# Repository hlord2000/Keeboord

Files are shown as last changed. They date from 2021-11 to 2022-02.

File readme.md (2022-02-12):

# Keeboord
## Created for the [Mechanical Keyboard Club at Georgia Tech](https://www.instagram.com/gt.keyboards)
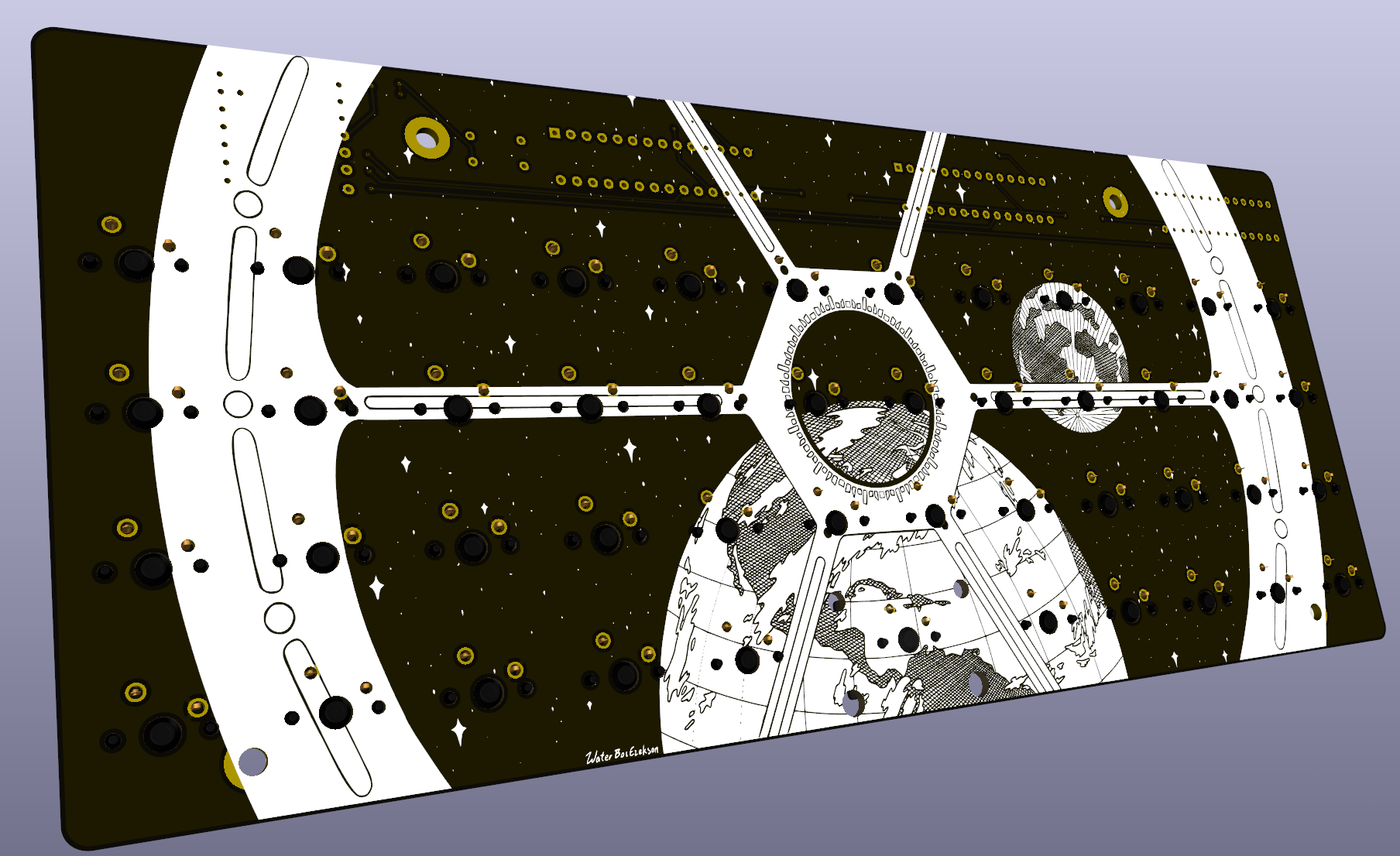
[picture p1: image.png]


This is a mechanical keyboard for Cherry switches.  It utilizes no diodes, instead registering button presses by using I2C I/O expanders.

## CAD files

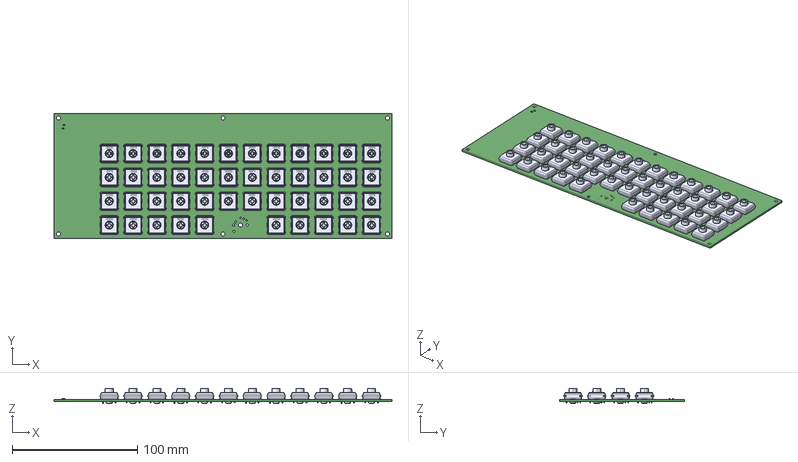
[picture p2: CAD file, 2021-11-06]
Hardware/keyboard.step
270.0 x 100.0 x 11.9 mm
AB2_SO28_W x 4

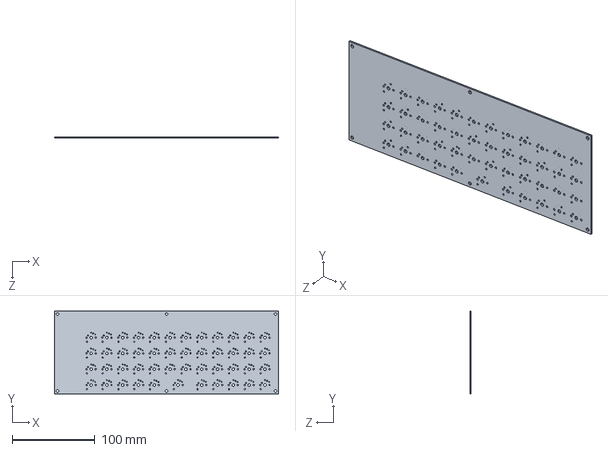
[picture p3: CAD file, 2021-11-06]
Case/COMPOUND_2.STEP
270.0 x 100.0 x 1.60 mm

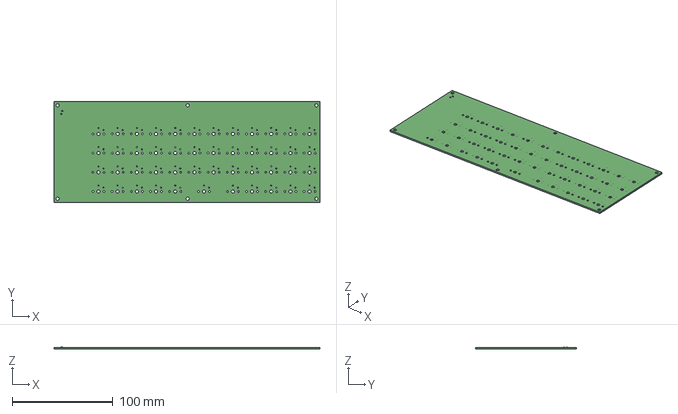
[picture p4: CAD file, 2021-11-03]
Case/keyboard.step
264.0 x 100.0 x 2.10 mm

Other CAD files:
Case/R_0603_1608Metric.SLDASM
Case/Kailh_PG1353.SLDASM
Case/SOLID.SLDPRT
Case/COMPOUND.SLDPRT
Case/COMPOUND_2.SLDPRT
Case/keyboard.SLDASM

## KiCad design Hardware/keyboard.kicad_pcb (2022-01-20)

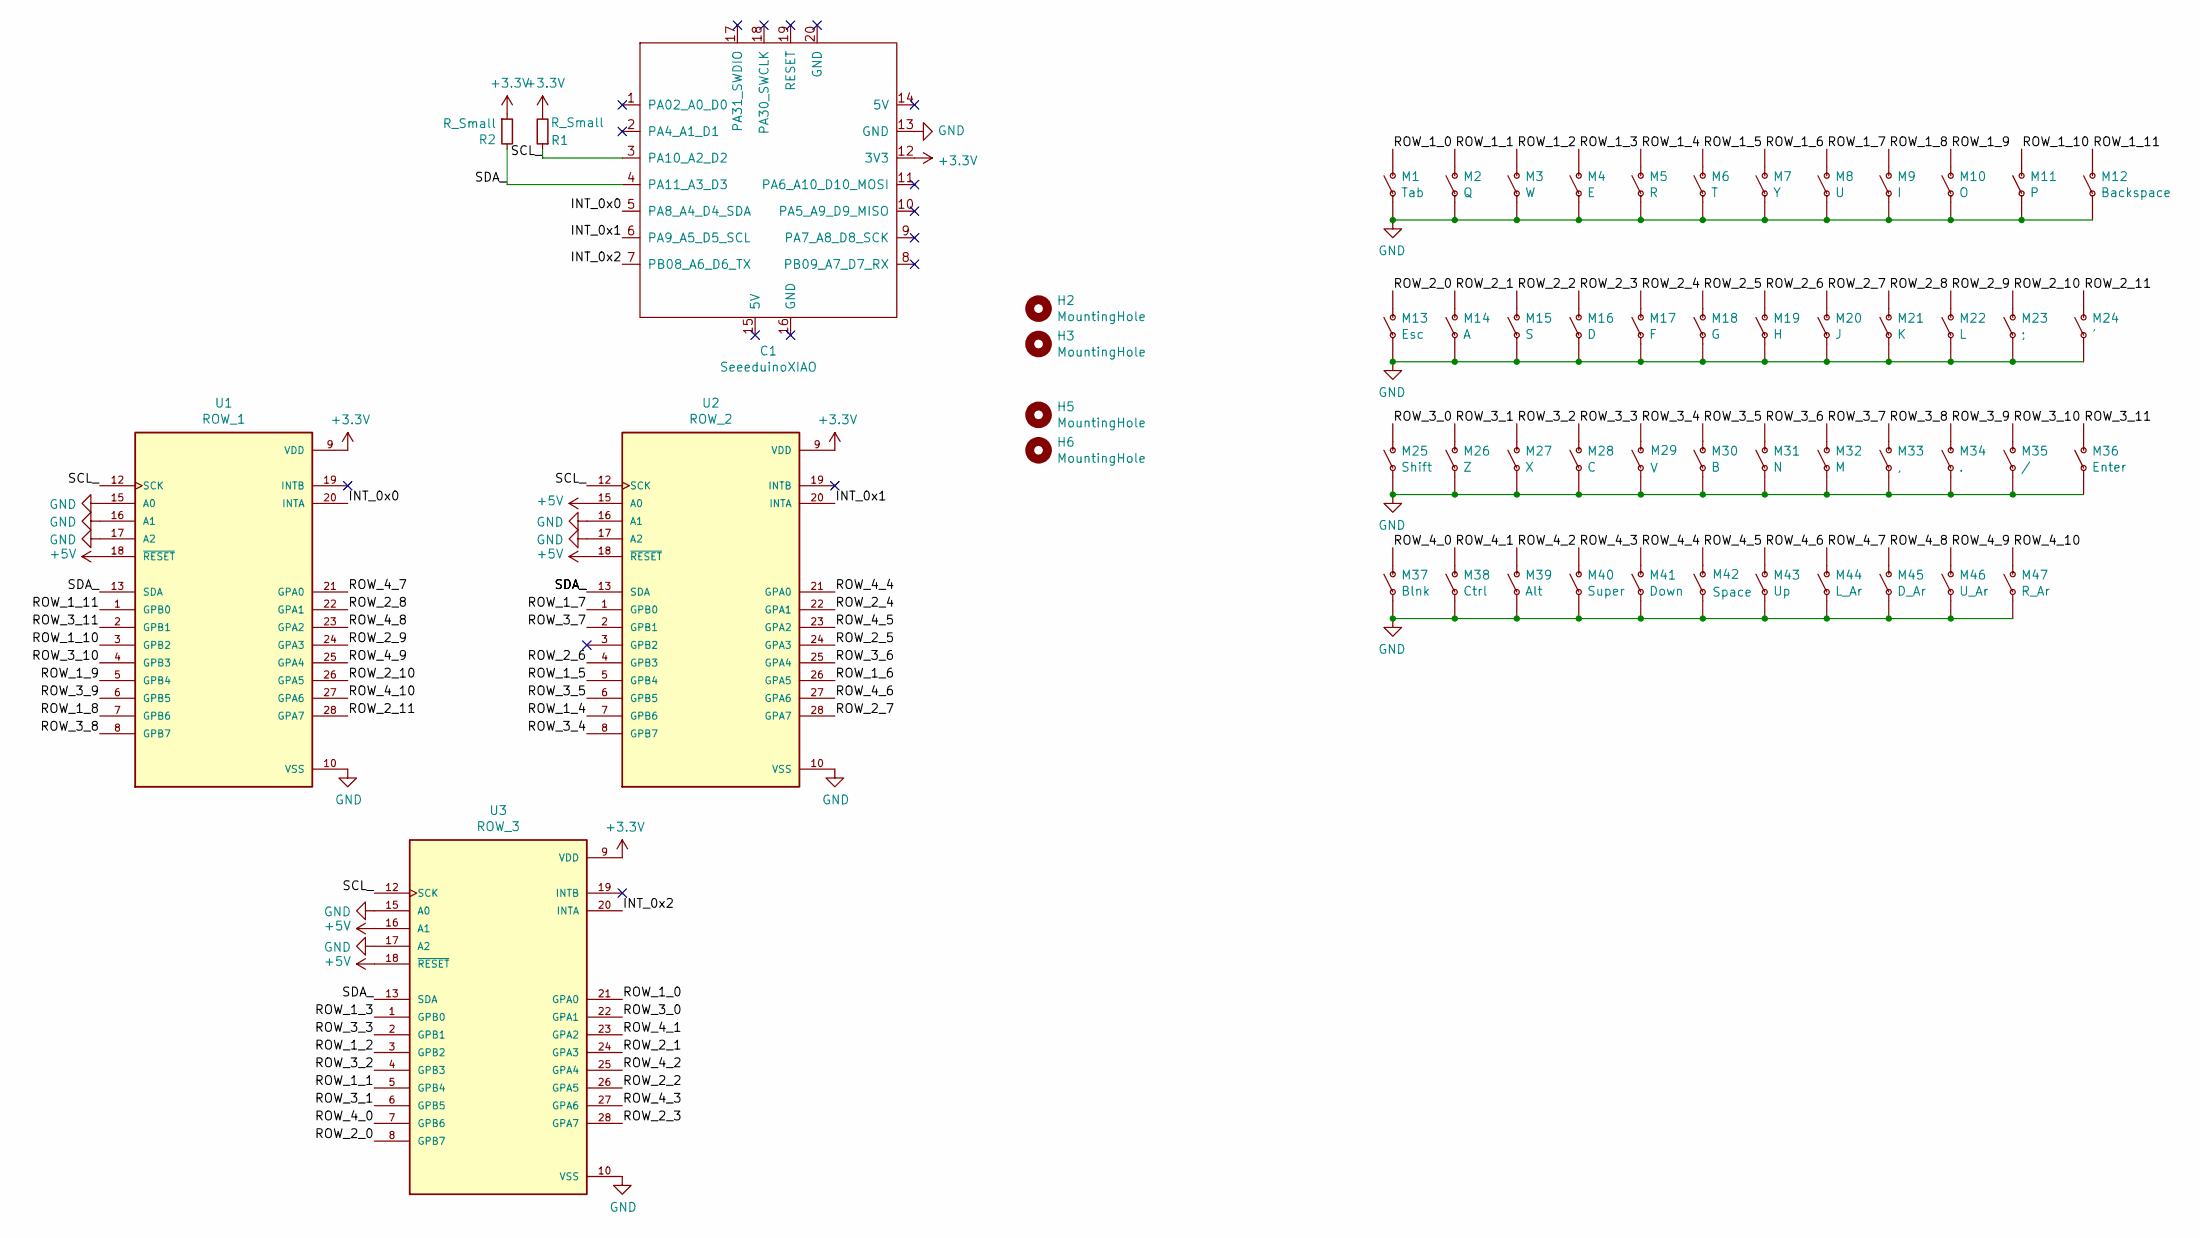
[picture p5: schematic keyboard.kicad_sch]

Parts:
C1: SeeeduinoXIAO; SeeeduinoXIAO-MOUDLE14P-2.54-21X17.8MM
H2, H3, H5, H6: MountingHole; MountingHole_3.2mm_M3_Pad
M1: Tab; SW_Cherry_MX_1.00u_PCB
M2: Q; SW_Cherry_MX_1.00u_PCB
M3: W; SW_Cherry_MX_1.00u_PCB
M4: E; SW_Cherry_MX_1.00u_PCB
M5: R; SW_Cherry_MX_1.00u_PCB
M6: T; SW_Cherry_MX_1.00u_PCB
M7: Y; SW_Cherry_MX_1.00u_PCB
M8: U; SW_Cherry_MX_1.00u_PCB
M9: I; SW_Cherry_MX_1.00u_PCB
M10: O; SW_Cherry_MX_1.00u_PCB
M11: P; SW_Cherry_MX_1.00u_PCB
M12: Backspace; SW_Cherry_MX_1.00u_PCB
M13: Esc; SW_Cherry_MX_1.00u_PCB
M14: A; SW_Cherry_MX_1.00u_PCB
M15: S; SW_Cherry_MX_1.00u_PCB
M16: D; SW_Cherry_MX_1.00u_PCB
M17: F; SW_Cherry_MX_1.00u_PCB
M18: G; SW_Cherry_MX_1.00u_PCB
M19: H; SW_Cherry_MX_1.00u_PCB
M20: J; SW_Cherry_MX_1.00u_PCB
M21: K; SW_Cherry_MX_1.00u_PCB
M22: L; SW_Cherry_MX_1.00u_PCB
M23: ;; SW_Cherry_MX_1.00u_PCB
M24: '; SW_Cherry_MX_1.00u_PCB
M25: Shift; SW_Cherry_MX_1.00u_PCB
M26: Z; SW_Cherry_MX_1.00u_PCB
M27: X; SW_Cherry_MX_1.00u_PCB
M28: C; SW_Cherry_MX_1.00u_PCB
M29: V; SW_Cherry_MX_1.00u_PCB
M30: B; SW_Cherry_MX_1.00u_PCB
M31: N; SW_Cherry_MX_1.00u_PCB
M32: M; SW_Cherry_MX_1.00u_PCB
M33: ,; SW_Cherry_MX_1.00u_PCB
M34: .; SW_Cherry_MX_1.00u_PCB
M35: /; SW_Cherry_MX_1.00u_PCB
M36: Enter; SW_Cherry_MX_1.00u_PCB
M37: Blnk; SW_Cherry_MX_1.00u_PCB
M38: Ctrl; SW_Cherry_MX_1.00u_PCB
M39: Alt; SW_Cherry_MX_1.00u_PCB
M40: Super; SW_Cherry_MX_1.00u_PCB
M41: Down; SW_Cherry_MX_1.00u_PCB
M42: Space; SW_Cherry_MX_2.00u_PCB
M43: Up; SW_Cherry_MX_1.00u_PCB
M44: L_Ar; SW_Cherry_MX_1.00u_PCB
M45: D_Ar; SW_Cherry_MX_1.00u_PCB
M46: U_Ar; SW_Cherry_MX_1.00u_PCB
M47: R_Ar; SW_Cherry_MX_1.00u_PCB
R1, R2: R_Small; R_Axial_DIN0204_L3.6mm_D1.6mm_P7.62mm_Horizontal
U1: ROW_1; DIP-28_W7.62mm
U2: ROW_2; DIP-28_W7.62mm
U3: ROW_3; DIP-28_W7.62mm

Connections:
+3V3: C1.12 (3V3), R1.2, R2.1, U1.9 (VDD), U1.18 (~RESET), U2.9 (VDD), U2.15 (A0), U2.18 (~RESET), U3.9 (VDD), U3.16 (A1), U3.18 (~RESET)
/INT_0x0: C1.5 (PA8_A4_D4_SDA), U1.20 (INTA)
/INT_0x1: C1.6 (PA9_A5_D5_SCL), U2.20 (INTA)
/INT_0x2: C1.7 (PB08_A6_D6_TX), U3.20 (INTA)
/ROW_1_0: M1.1 (O), U3.21 (GPA0)
/ROW_1_1: M2.1 (O), U3.5 (GPB4)
/ROW_1_2: M3.1 (O), U3.3 (GPB2)
/ROW_1_3: M4.1 (O), U3.1 (GPB0)
/ROW_1_4: M5.1 (O), U2.7 (GPB6)
/ROW_1_5: M6.1 (O), U2.5 (GPB4)
/ROW_1_6: M7.1 (O), U2.26 (GPA5)
/ROW_1_7: M8.1 (O), U2.1 (GPB0)
/ROW_1_8: M9.1 (O), U1.7 (GPB6)
/ROW_1_9: M10.1 (O), U1.5 (GPB4)
/ROW_1_10: M11.1 (O), U1.3 (GPB2)
/ROW_1_11: M12.1 (O), U1.1 (GPB0)
/ROW_2_0: M13.1 (O), U3.8 (GPB7)
/ROW_2_1: M14.1 (O), U3.24 (GPA3)
/ROW_2_2: M15.1 (O), U3.26 (GPA5)
/ROW_2_3: M16.1 (O), U3.28 (GPA7)
/ROW_2_4: M17.1 (O), U2.22 (GPA1)
/ROW_2_5: M18.1 (O), U2.24 (GPA3)
/ROW_2_6: M19.1 (O), U2.4 (GPB3)
/ROW_2_7: M20.1 (O), U2.28 (GPA7)
/ROW_2_8: M21.1 (O), U1.22 (GPA1)
/ROW_2_9: M22.1 (O), U1.24 (GPA3)
/ROW_2_10: M23.1 (O), U1.26 (GPA5)
/ROW_2_11: M24.1 (O), U1.28 (GPA7)
/ROW_3_0: M25.1 (O), U3.22 (GPA1)
/ROW_3_1: M26.1 (O), U3.6 (GPB5)
/ROW_3_2: M27.1 (O), U3.4 (GPB3)
/ROW_3_3: M28.1 (O), U3.2 (GPB1)
/ROW_3_4: M29.1 (O), U2.8 (GPB7)
/ROW_3_5: M30.1 (O), U2.6 (GPB5)
/ROW_3_6: M31.1 (O), U2.25 (GPA4)
/ROW_3_7: M32.1 (O), U2.2 (GPB1)
/ROW_3_8: M33.1 (O), U1.8 (GPB7)
/ROW_3_9: M34.1 (O), U1.6 (GPB5)
/ROW_3_10: M35.1 (O), U1.4 (GPB3)
/ROW_3_11: M36.1 (O), U1.2 (GPB1)
/ROW_4_0: M37.1 (O), U3.7 (GPB6)
/ROW_4_1: M38.1 (O), U3.23 (GPA2)
/ROW_4_2: M39.1 (O), U3.25 (GPA4)
/ROW_4_3: M40.1 (O), U3.27 (GPA6)
/ROW_4_4: M41.1 (O), U2.21 (GPA0)
/ROW_4_5: M42.1 (O), U2.23 (GPA2)
/ROW_4_6: M43.1 (O), U2.27 (GPA6)
/ROW_4_7: M44.1 (O), U1.21 (GPA0)
/ROW_4_8: M45.1 (O), U1.23 (GPA2)
/ROW_4_9: M46.1 (O), U1.25 (GPA4)
/ROW_4_10: M47.1 (O), U1.27 (GPA6)
/SCL_: C1.3 (PA10_A2_D2), R1.1, U1.12 (SCK), U2.12 (SCK), U3.12 (SCK)
/SDA_: C1.4 (PA11_A3_D3), R2.2, U1.13 (SDA), U2.13 (SDA), U3.13 (SDA)
GND: C1.13 (GND), M1.2, M2.2, M3.2, M4.2, M5.2, M6.2, M7.2, M8.2, M9.2, M10.2, M11.2, M12.2, M13.2, M14.2, M15.2, M16.2, M17.2, M18.2, M19.2, M20.2, M21.2, M22.2, M23.2, M24.2, M25.2, M26.2, M27.2, M28.2, M29.2, M30.2, M31.2, M32.2, M33.2, M34.2, M35.2, M36.2, M37.2, M38.2, M39.2, M40.2, M41.2, M42.2, M43.2, M44.2, M45.2, M46.2, M47.2, U1.10 (VSS), U1.15 (A0), U1.16 (A1), U1.17 (A2), U2.10 (VSS), U2.16 (A1), U2.17 (A2), U3.10 (VSS), U3.15 (A0), U3.17 (A2)

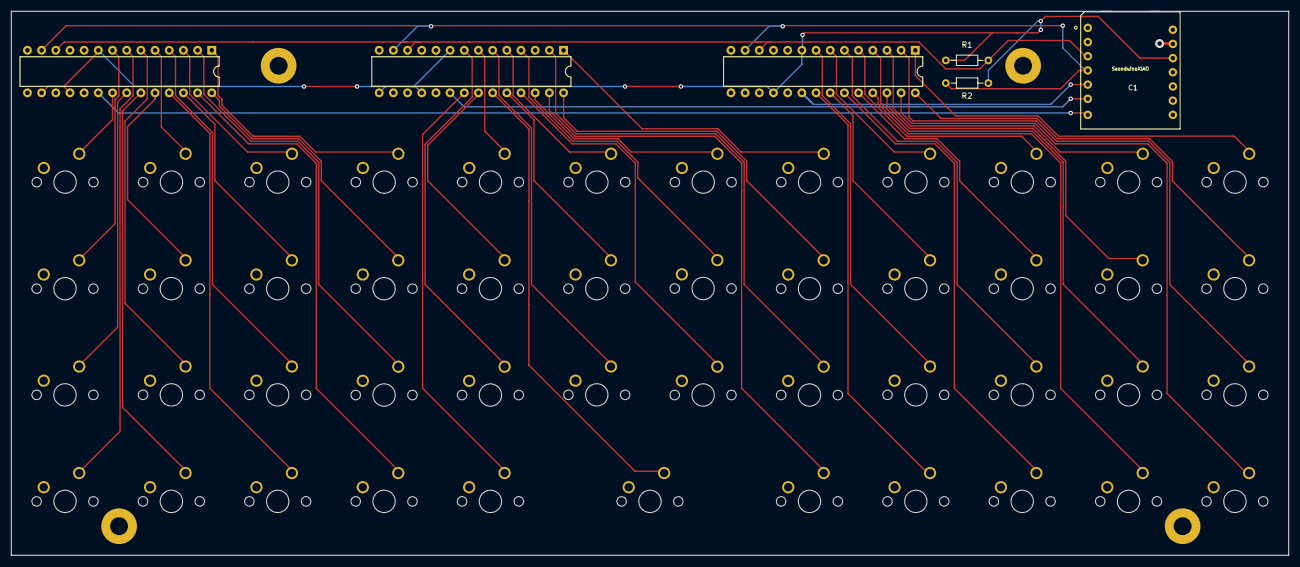
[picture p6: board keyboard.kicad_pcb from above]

Board: 2 copper layers, 228.8 x 97.4 mm, 57 parts (0 on the bottom side), 54 nets.

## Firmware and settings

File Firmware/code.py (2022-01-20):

import time
import board
import busio
import digitalio
import usb_hid
from adafruit_hid.keyboard import Keyboard
from adafruit_hid.keyboard_layout_us import KeyboardLayoutUS
from adafruit_hid.keycode import Keycode
from adafruit_mcp230xx.mcp23017 import MCP23017

# To use default I2C bus (most boards)
i2c = busio.I2C(board.A2,board.A3,frequency=400000)

mcp = [MCP23017(i2c, address = expander) for expander in [0x22, 0x20, 0x21]]

mcp_pins = []

for expander in mcp:
    for pin in range(0,16):
        mcp_pins.append(expander.get_pin(pin))
        
for i in mcp_pins:
    i.pull = digitalio.Pull.UP
    
keyboard = Keyboard(usb_hid.devices)
layout = KeyboardLayoutUS(keyboard)
layers = [
[
Keycode.ESCAPE, Keycode.Q, Keycode.W, Keycode.E, Keycode.R, Keycode.T, Keycode.Y, Keycode.U, Keycode.I, Keycode.O, Keycode.P, Keycode.BACKSPACE,
Keycode.TAB, Keycode.A, Keycode.S, Keycode.D, Keycode.F, Keycode.G, Keycode.H, Keycode.J, Keycode.K, Keycode.L, Keycode.SEMICOLON, Keycode.ENTER,
Keycode.SHIFT, Keycode.Z, Keycode.X, Keycode.C, Keycode.V, Keycode.B, Keycode.N, Keycode.M, Keycode.COMMA, Keycode.PERIOD, Keycode.FORWARD_SLASH, Keycode.QUOTE,
Keycode.LEFT_CONTROL, Keycode.LEFT_GUI, Keycode.LEFT_ALT, Keycode.F20, "DOWN", Keycode.SPACE, "UP", Keycode.APPLICATION, Keycode.RIGHT_GUI, Keycode.RIGHT_ALT, Keycode.RIGHT_CONTROL
],

[
Keycode.ESCAPE, Keycode.ONE, Keycode.TWO, Keycode.THREE, Keycode.FOUR, Keycode.FIVE, Keycode.SIX, Keycode.SEVEN, Keycode.EIGHT, Keycode.NINE, Keycode.ZERO, Keycode.BACKSPACE,
Keycode.TAB, Keycode.MINUS, Keycode.EQUALS, Keycode.LEFT_BRACKET, Keycode.RIGHT_BRACKET, Keycode.G, Keycode.LEFT_ARROW, Keycode.DOWN_ARROW, Keycode.UP_ARROW, Keycode.RIGHT_ARROW, Keycode.SEMICOLON, Keycode.QUOTE,
Keycode.SHIFT, Keycode.Z, Keycode.X, Keycode.C, Keycode.V, Keycode.B, Keycode.N, Keycode.M, Keycode.COMMA, Keycode.PERIOD, Keycode.FORWARD_SLASH, Keycode.SHIFT,
Keycode.LEFT_CONTROL, Keycode.LEFT_GUI, Keycode.LEFT_ALT, Keycode.F20, "DOWN", Keycode.SPACE, "UP", Keycode.APPLICATION, Keycode.RIGHT_GUI, Keycode.RIGHT_ALT, Keycode.RIGHT_CONTROL
],

[
Keycode.F1, Keycode.F2, Keycode.F3, Keycode.F4, Keycode.F5, Keycode.F6, Keycode.F7, Keycode.F8, Keycode.F9, Keycode.F10, Keycode.F11, Keycode.F12,
Keycode.TAB, Keycode.A, Keycode.S, Keycode.D, Keycode.F, Keycode.G, Keycode.H, Keycode.J, Keycode.K, Keycode.L, Keycode.SEMICOLON, Keycode.ENTER,
Keycode.SHIFT, Keycode.Z, Keycode.X, Keycode.C, Keycode.V, Keycode.B, Keycode.N, Keycode.M, Keycode.COMMA, Keycode.PERIOD, Keycode.FORWARD_SLASH, Keycode.QUOTE,
Keycode.LEFT_CONTROL, Keycode.LEFT_GUI, Keycode.LEFT_ALT, Keycode.F20, "DOWN", Keycode.SPACE, "UP", Keycode.APPLICATION, Keycode.RIGHT_GUI, Keycode.RIGHT_ALT, Keycode.RIGHT_CONTROL
]

]
layer_index = 0
keeboord_matrix = layers[layer_index]



matrix_converted = [
{
    0:44,
    1:21,
    2:45,
    3:22,
    4:46,
    5:23,
    6:47,
    7:24,
    8:12,
    9:36,
    10:11,
    11:35,
    12:10,
    13:34,
    14:9,
    15:33
},
{
    0:41,
    1:17,
    2:42,
    3:18,
    4:31,
    5:7,
    6:43,
    7:20,
    8:8,
    9:32,
    10:-1,
    11:19,
    12:6,
    13:30,
    14:5,
    15:29
},
{
    0:1,
    1:25,
    2:38,
    3:14,
    4:39,
    5:15,
    6:40,
    7:16,
    8:4,
    9:28,
    10:3,
    11:27,
    12:2,
    13:26,
    14:37,
    15:13
}
]
        
key_state = [0,0,0]
prev_state = [0,0,0]
held = []
layer_index = 0

while True:
    try:
        for i, expander in enumerate(mcp):    
            key_state[i-1] = 65535 - (((expander.gpiob) << 8) | (expander.gpioa))
        
        for i in range(0,3):
            for j in range(0,16):
                key_code = keeboord_matrix[matrix_converted[i][j]-1]
                key_pressed = int((key_state[i]) >> (j)) & 1
                
                if all([key_pressed, key_code == "UP", key_code not in held]):
                    if layer_index + 1 > 2:
                        layer_index = 0
                    else:
                        layer_index = layer_index + 1
                    keeboord_matrix = layers[layer_index]
                    held.append(key_code)
                    continue
                elif all([key_pressed, key_code == "DOWN", key_code not in held]):
                    if layer_index - 1 < 0:
                        layer_index = 2
                    else:
                        layer_index = layer_index - 1
                    keeboord_matrix = layers[layer_index]
                    held.append(key_code)
                    continue

                if all([key_pressed, key_code not in held]):
                    keyboard.press(key_code)
                    held.append(key_code)
                elif all([not key_pressed, key_code in held]):
                    held.remove(key_code)
                    if any([key_code == "UP", key_code == "DOWN"]):
                        continue
                    keyboard.release(key_code)
    except ValueError:
        pass

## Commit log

2021-10-29 Initial hardware Rev. 1
    [1,118.step, keyboard.kicad_pcb, keyboard.sch]
2021-10-29 small revision
    [keyboard.kicad_pcb]
2021-10-29 Reworked layout, everything is aligned now.
    [keyboard.kicad_pcb]
2021-10-30 Prototype 1
    [keyboard-B_Cu.gbr, keyboard-B_Mask.gbr, keyboard-B_Paste.gbr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]
2021-10-30 Cleaned up file structure.
    [1,118.step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]
2021-11-02 South-facing switch change
    [keyboard.kicad_pcb, keyboard.sch]
2021-11-02 More rerouting.
    [keyboard.sch]
2021-11-03 Added MX switch compatibility
    [keyboard.step]
2021-11-07 Moved location of I/O
    [keyboard.kicad_pcb, keyboard.sch]
2021-11-07 updated output files.
    [keyboard-B_Cu.gbr, keyboard-B_Mask.gbr, keyboard-B_Paste.gbr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]
2021-11-12 Conversion to all through-hole components.
    [keyboard-B_Cu.gbr, keyboard-B_Mask.gbr, keyboard-B_Paste.gbr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]
2021-11-23 Swapped SDA and SCL pins.
    [keyboard.kicad_pcb, keyboard.sch]
2022-01-22 Final revision of hardware, software, art.
    [keyboard-B_Cu.gbr, keyboard-B_Mask.gbr, keyboard-B_Paste.gbr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]
